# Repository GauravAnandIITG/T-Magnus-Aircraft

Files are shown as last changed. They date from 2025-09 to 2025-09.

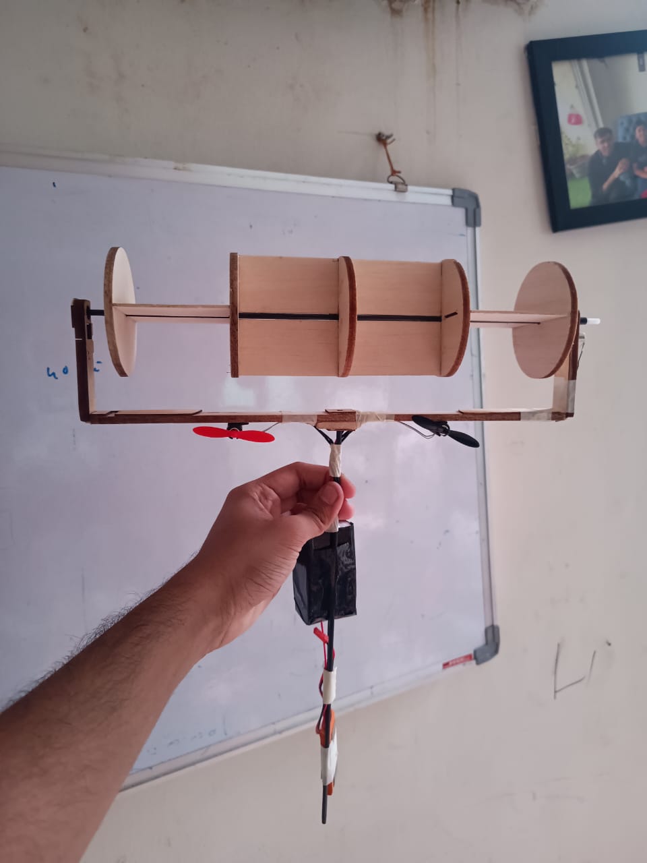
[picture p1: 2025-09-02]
WhatsApp Image 2025-09-02 at 19.15.58_4bbd0eb5.jpg

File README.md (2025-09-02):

# ✈️ Flettner Aircraft (T-Magnus Plane)

A prototype rotor airplane developed in collaboration with **Kalam Labs, Lucknow**.  
This project explores the concept of using the **Magnus Effect** for lift generation through a rotating cylinder (**Flettner rotor**) instead of conventional wings.

---

## 📌 Overview

The **Flettner Aircraft (T-Magnus Plane)** was ideated as part of the **Techmaker Program**, aiming to create engaging and educational aerospace prototypes compatible with **Kalam Labs' in-house KL Microcontroller**.

---

## ❓ What is a Flettner Aircraft?

A **Flettner airplane** is a type of rotor aircraft that uses a **Flettner rotor** for lift.

- The rotor is a **spinning cylinder** with circular end plates.  
- As the aircraft moves forward, the **Magnus Effect** generates lift.

🔗 Learn more:
- [Rotor airplane](https://en.wikipedia.org/wiki/Rotor_aircraft)  
- [Flettner rotor](https://en.wikipedia.org/wiki/Flettner_rotor)  
- [Magnus effect](https://en.wikipedia.org/wiki/Magnus_effect)  

---

## 🌪️ What is the Magnus Effect?

The **Magnus Effect** occurs when a spinning object moves through a fluid (air or liquid).

- A **lift force** acts perpendicular to the direction of motion.  
- The force depends on the **speed and direction of rotation**.  
- Commonly observed in **sports balls, turbines, and experimental aircraft**.

---

## 🛠️ Project Timeline & Iterations

### 📌 Ideation
- **September 2024**: Concept proposed to **Kalam Labs** for demonstration using their **KL Microcontroller**.  
- Confirmed by **Kalam Labs Co-Founders** for their showcase program.  

---

### 🔧 Iteration 1
**Components:**
- Propeller motor: `Sunsky 2200 KV`  
- Rotor motor: `Emax 935 KV`  
- Gear mechanism replaced with pulley-belt system  

**Issue:**  
- Rotor shaft airflow blocked by propeller → ❌ No lift generated  

---

### 🔧 Iteration 2
**Changes:**
- Propeller repositioned **below rotor axis**  

**Issue:**  
- Torque instability during takeoff → ❌ Uncontrollable spinning & crash  

**Fix:**  
- Extended vertical rod + lowered battery → ✅ Better center of gravity  

**Outcome:**  
- Improved stability, but **lift < weight**  

---

### 🔧 Iteration 3
**Changes:**
- Integrated with **KL Microcontroller**  
- Reduced weight: **400g → 85g**  

**Outcome:**  
- More efficient system, but still **insufficient lift for flight**  

---

## 🎤 Showcase

- 📅 **October 25, 2024**  
- Presented at the **Techmaker Program Showcase** organized by **Kalam Labs**  
- Demonstrated **concept + iterations** to judges and attendees  

---
⭐ If you find this project interesting, don’t forget to **star this repo**!

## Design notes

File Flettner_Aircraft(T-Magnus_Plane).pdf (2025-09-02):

# Flettner Aircraft(T-Magnus Plane)

### Project in association with Kalam Labs, Lucknow

## What is a Flettner Aircraft:

A Flettner airplane is a type of rotor airplane (https://en.wikipedia.org/wiki/Rotor_airplane) which uses a Flettner rotor (https://en.wikipedia.org/wiki/Flettner_rotor) to provide lift. The rotor comprises a spinning cylinder with circular end plates and, in an aircraft, spins about a spanwise horizontal axis. When the aircraft moves forward, the Magnus effect (https://en.wikipedia.org/wiki/Magnus_effect) creates lift.

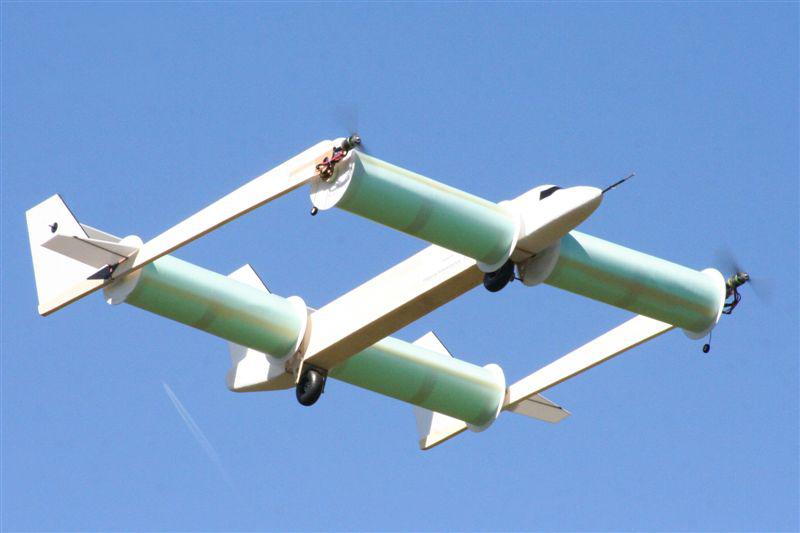
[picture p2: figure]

## What is Magnus effect:

The Magnus effect is a phenomenon that occurs when a spinning (https://en.wikipedia.org/wiki/Spin_(geometry)) object (https://en.wikipedia.org/wiki/Object_(physics)) is moving through a fluid. (https://en.wikipedia.org/wiki/Fluid) A lift force (https://en.wikipedia.org/wiki/Lift_(force)) acts on the spinning object and its path may be

Flettner Aircraft(T | -Magnus Plane) | 1

deflected in a manner not present when it is not spinning. The strength and direction of the Magnus force is dependent on the speed and direction of the rotation of the object

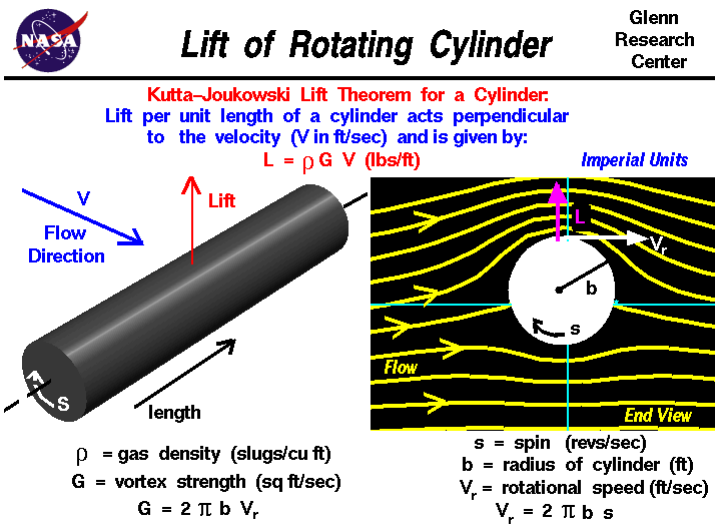
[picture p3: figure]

## Ideation of Project:

September, 2024
In Last week of September Kalam Labs contacted us for Ideas that gonna attract kids and compatible with their in house developed KL Microcontroller.
Then we came up with this idea and discussed it with Kalam Labs Co-Founders and confirm this idea for their showcasing.

## Iterations of this project:

### 1st Iteration:

Firstly made a aircraft with our resources.
Propeller motor- Sunsky 2200 kv motor

Rotor motor- Emax 935 kv motor
firstly we used gears for rotor but they didn’t worked out so we used pulley belt system.
Rotor axis and propeller motor was on the same line.

This version is unable to create lift because due to propeller, rotor shaft was unable to get air around it.

### 2nd iteration:

We moved propeller slightly lower than its previous position.

From this improvement we get another problem of torque, During takeoff, an excessive torque reaction caused the aircraft to rotate uncontrollably about the rotor axis, ultimately leading to a crash.

To counteract the torque-induced rotation, we extended the vertical rod and repositioned the battery at its lowest point. This adjustment lowered the aircraft's center of gravity, enhancing stability and reducing unwanted rotational motion during takeoff.
We tested this version at Kalam Labs and this didn’t takeoff due to low lift generation in comparison of weight.

### 3rd iteration:

We integrated our idea with KL microcontroller and developed our aircraft according to the limitations of their flight controller.
We reduced its size and significantly decreased its weight from 400g to 85g, improving efficiency and overall performance.

This version is still unable to achieve flight due to insufficient lift.


## Showcasing:

On October 25, 2024, we will pitch our project to the judges at the showcase event, where multiple teams invited for the Techmaker program will present their projects.

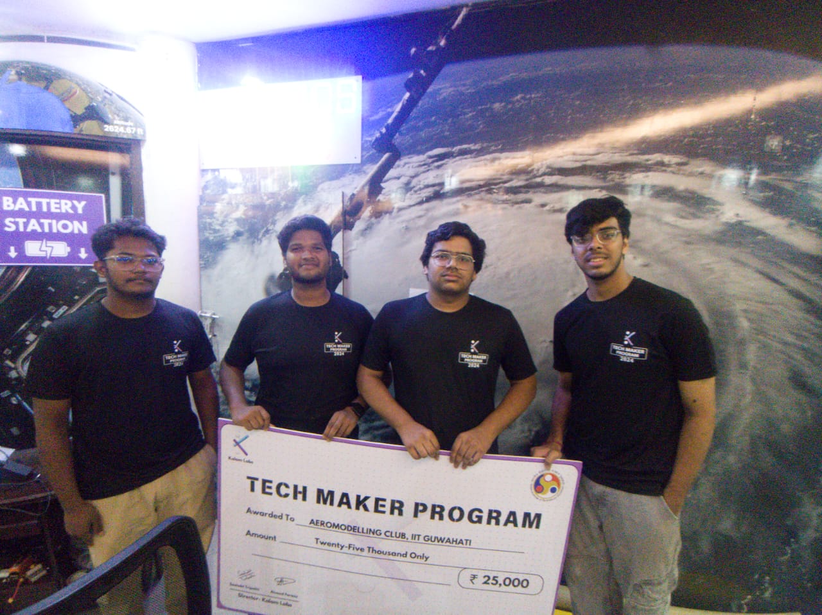
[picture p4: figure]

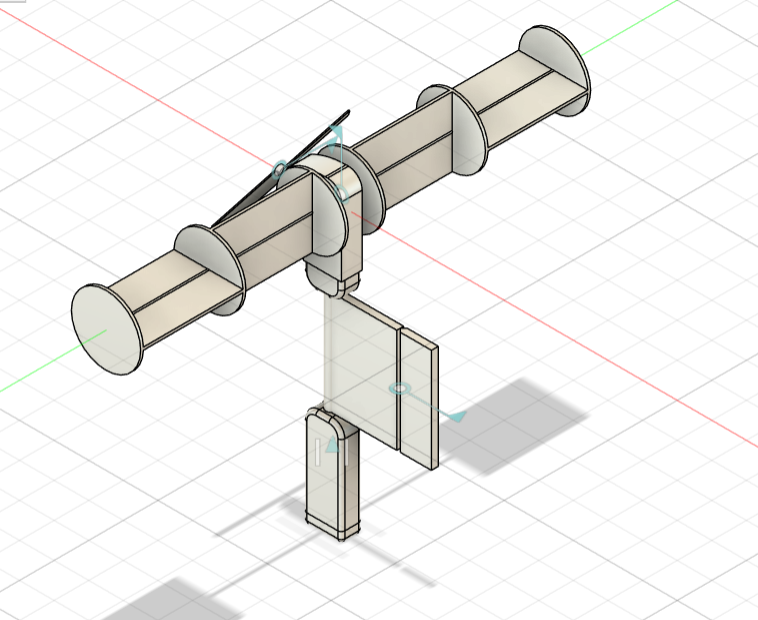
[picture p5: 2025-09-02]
Screenshot 2025-09-02 191432.png

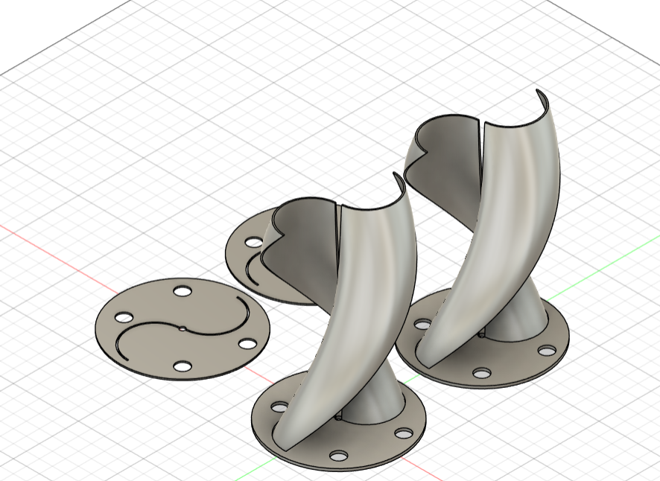
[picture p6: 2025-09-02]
Screenshot 2025-09-02 191446.png

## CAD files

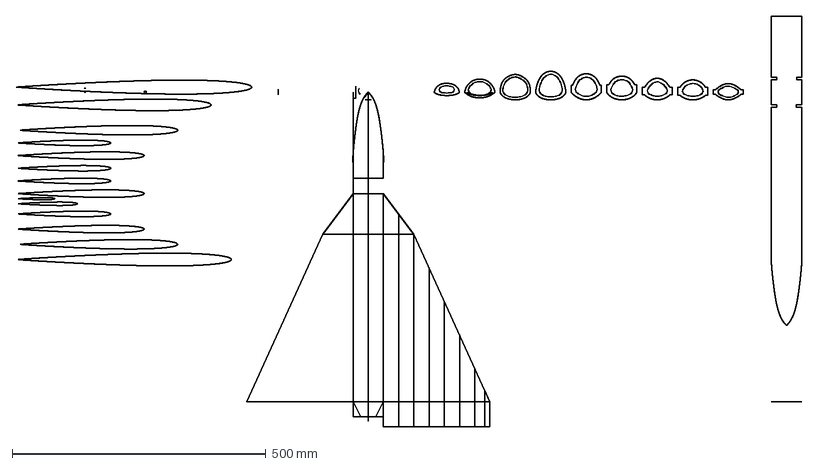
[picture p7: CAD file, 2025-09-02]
Ribber Wing.dxf
1549.2 x 810.0 mm

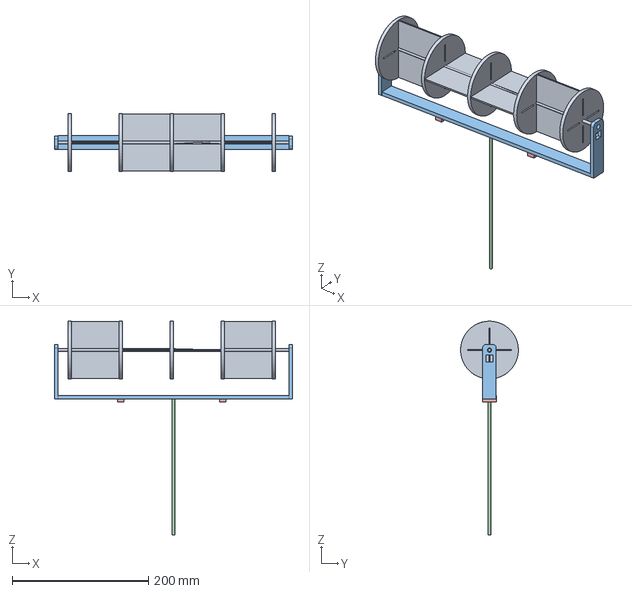
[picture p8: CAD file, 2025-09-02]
Circle v3.step
350.0 x 85.0 x 314.2 mm

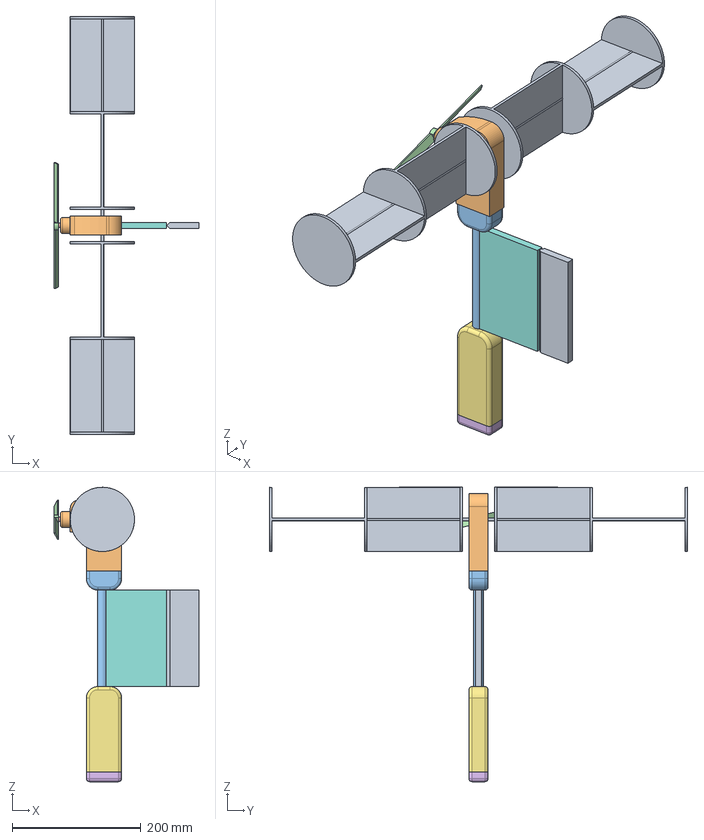
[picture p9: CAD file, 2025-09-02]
Plane (Magnus) v2.step
225.0 x 650.0 x 458.0 mm

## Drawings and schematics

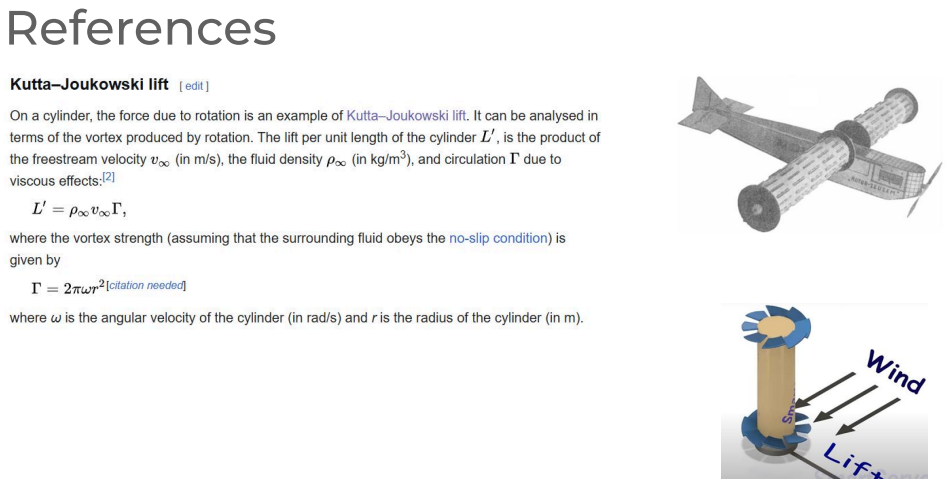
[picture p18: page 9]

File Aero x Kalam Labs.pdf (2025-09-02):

Aeromodelling Club,

# IITG

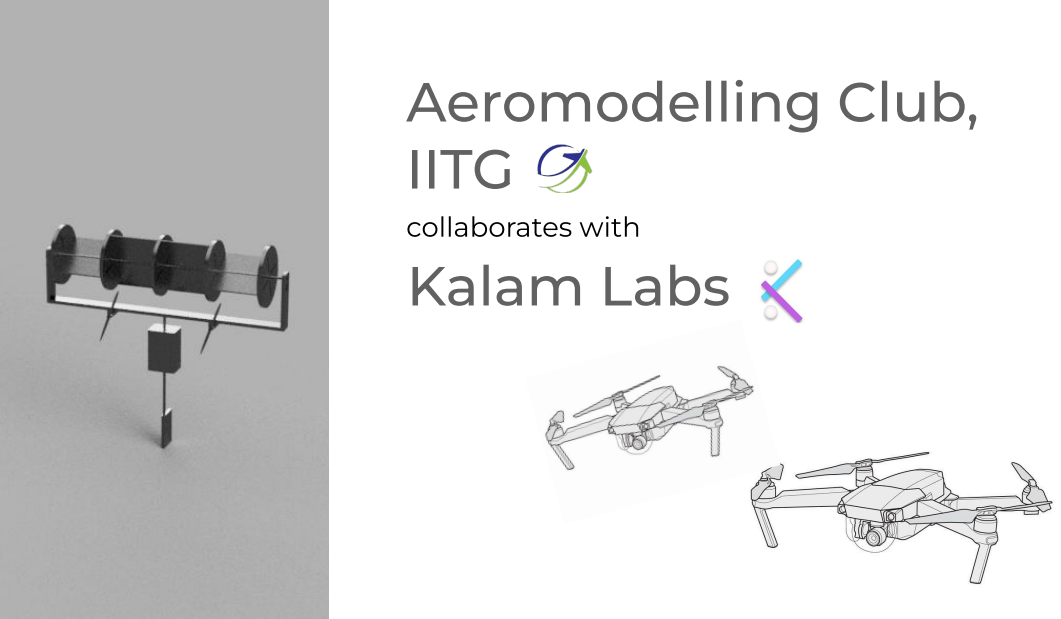
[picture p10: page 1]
collaborates with Kalam Labs

# Aeromodelling Club, IITG

## Soaring to New Heights

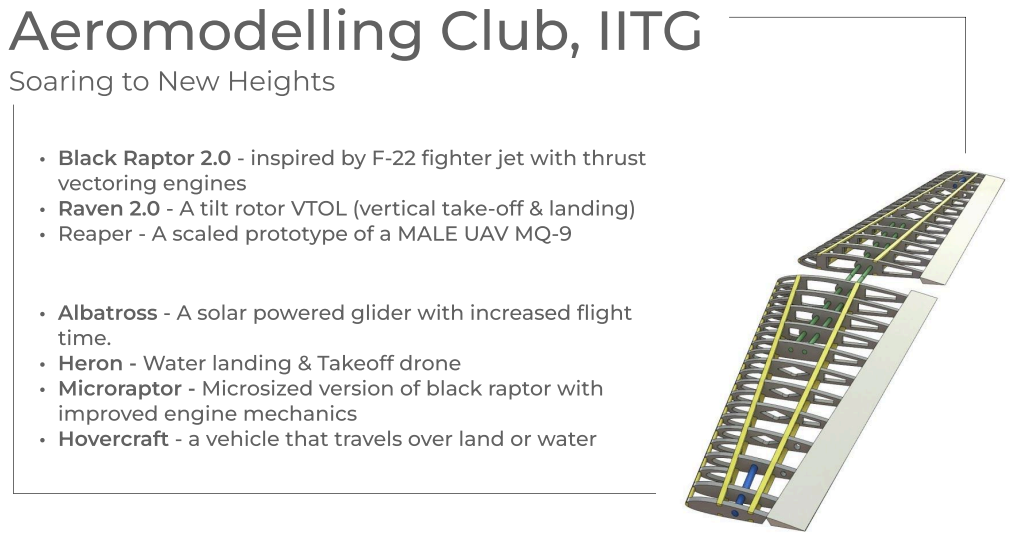
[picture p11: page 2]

m Black Raptor 2.0 - inspired by F-22 fighter jet with thrust
vectoring engineS
m Raven 2.0 - A tilt rotor VTOL (vertical take-off & landingB

m Reaper - A scaled prototype of a MALE UAV MQ-9

m Albatross - A solar powered glider with increased flight
time.~

m Heron - Water landing & Takeoff dron
m Microraptor - Microsized version of black raptor with
improved engine mechanicS
m Hovercraft - a vehicle that travels over land or water

# Aeromodelling Club, IITG

## Our Achievements

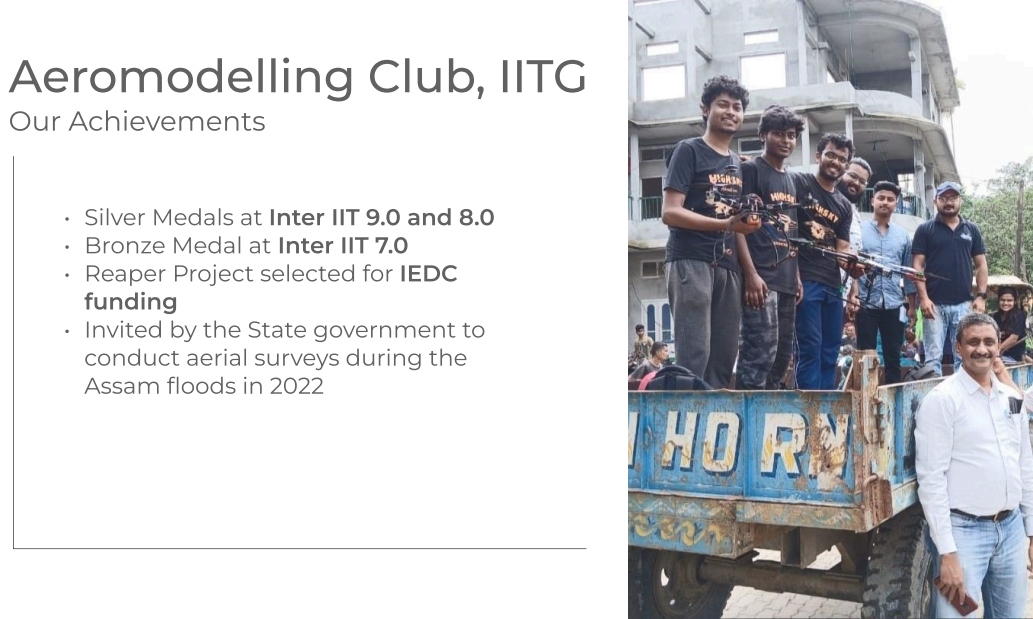
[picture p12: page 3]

< Silver Medals at Inter IIT 9.0 and 8.T
< Bronze Medal at Inter IIT 7.T
< Reaper Project selected for IEDC
fundin'
< Invited by the State government to
conduct aerial surveys during the
Assam floods in 2022

# T-Magnus effect Plane

# Where science meets fun

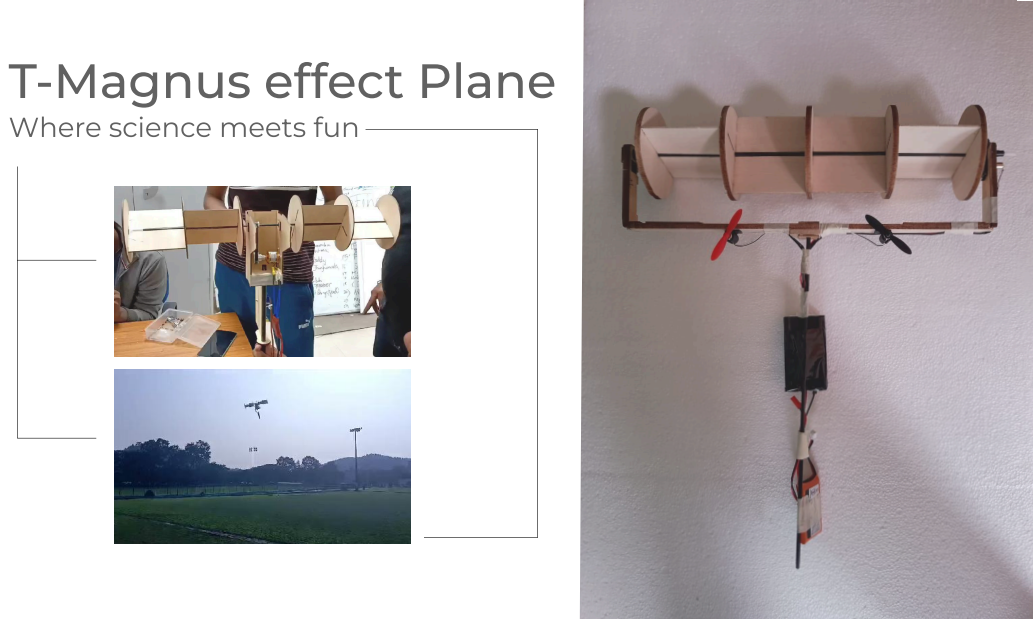
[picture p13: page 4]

# T-Magnus effect Plane

# Educational Value for Children

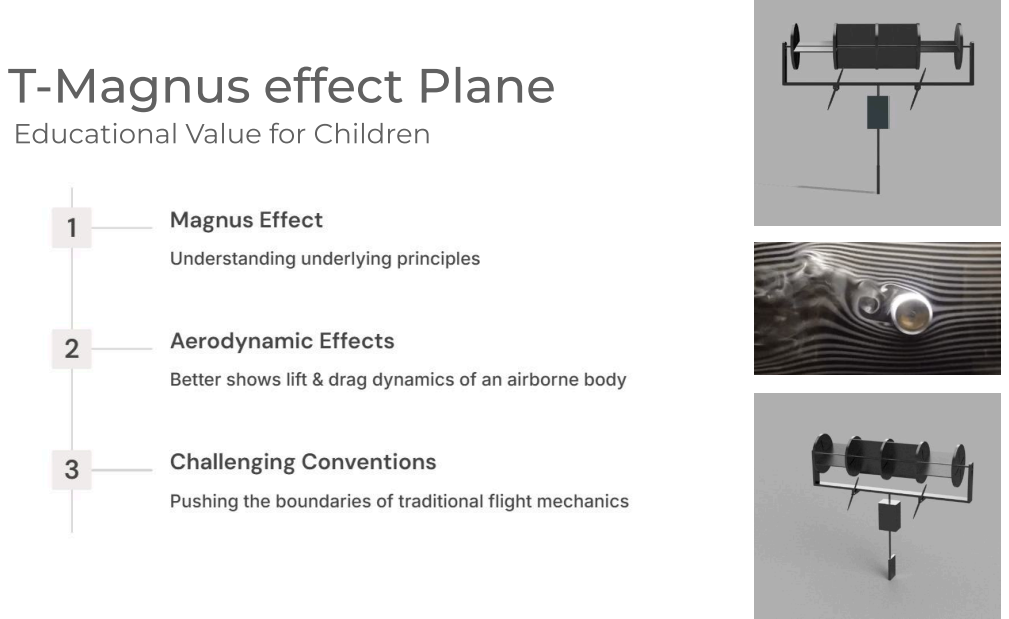
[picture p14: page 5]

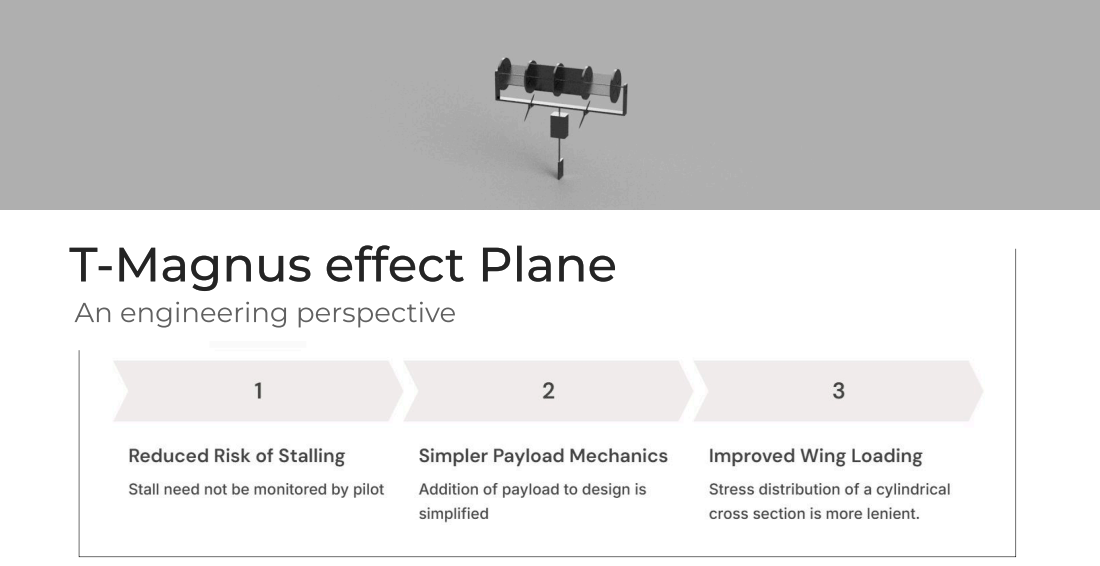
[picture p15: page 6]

T-Magnus effect Plane
An engineering perspective

# Flight Controller

## Implementing Kalam Labs FC into our plane

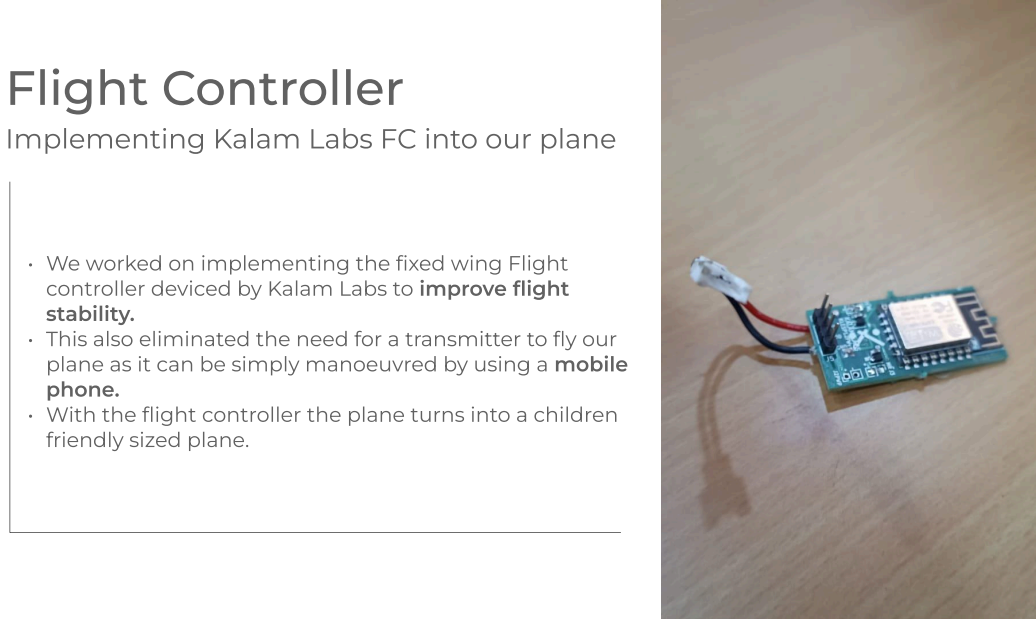
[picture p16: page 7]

> We worked on implementing the fixed wing Flight
controller deviced by Kalam Labs to improve flight
stability;
> This also eliminated the need for a transmitter to fly our
plane as it can be simply manoeuvred by using a mobile
phone;
> With the flight controller the plane turns into a children
friendly sized plane.

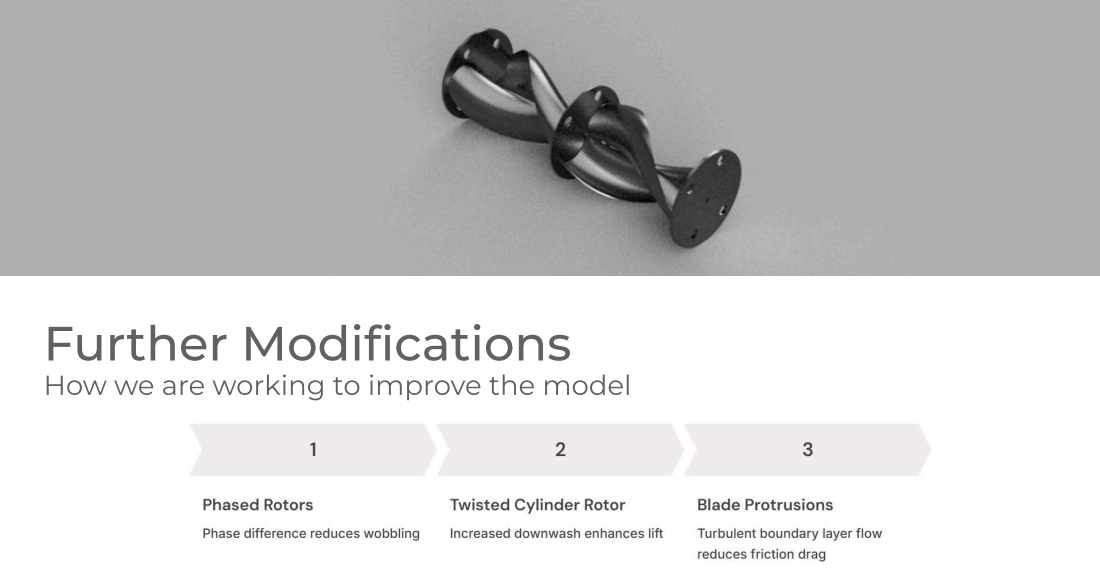
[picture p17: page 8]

Further Modifications
How we are working to improve the model

# References
